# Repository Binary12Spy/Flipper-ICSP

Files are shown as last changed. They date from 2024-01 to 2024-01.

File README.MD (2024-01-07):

# Flipper-ICSP

Shout out to [Speexvocon](https://github.com/Speexvocon) for his [FlipperZeroKiCadPart](https://github.com/Speexvocon/FlipperZeroKiCadPart) making this project a whole lot easier!

I wanted to make a module for the Flipper Zero that works with [AVR Flasher](https://lab.flipper.net/apps/avr_isp) and simplifies hooking up a AVR microcontroller for flashing.  
This module simply formats the pins used by AVR Flasher into standard 10 position and 6 position ICSP headers with the option to choose between 3v3, 5v, or no supplied voltage.  


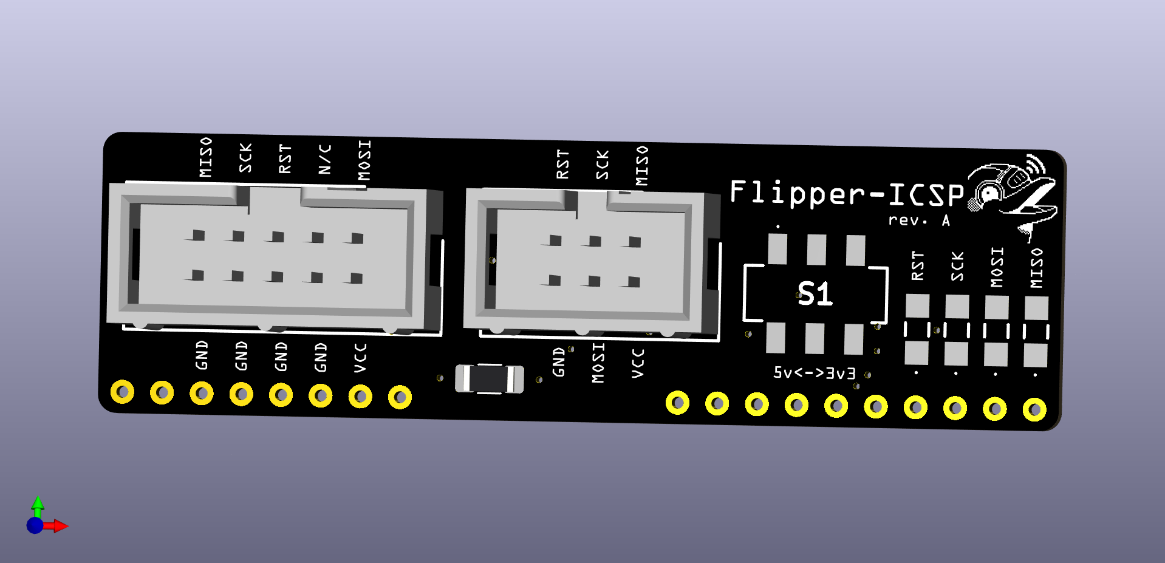
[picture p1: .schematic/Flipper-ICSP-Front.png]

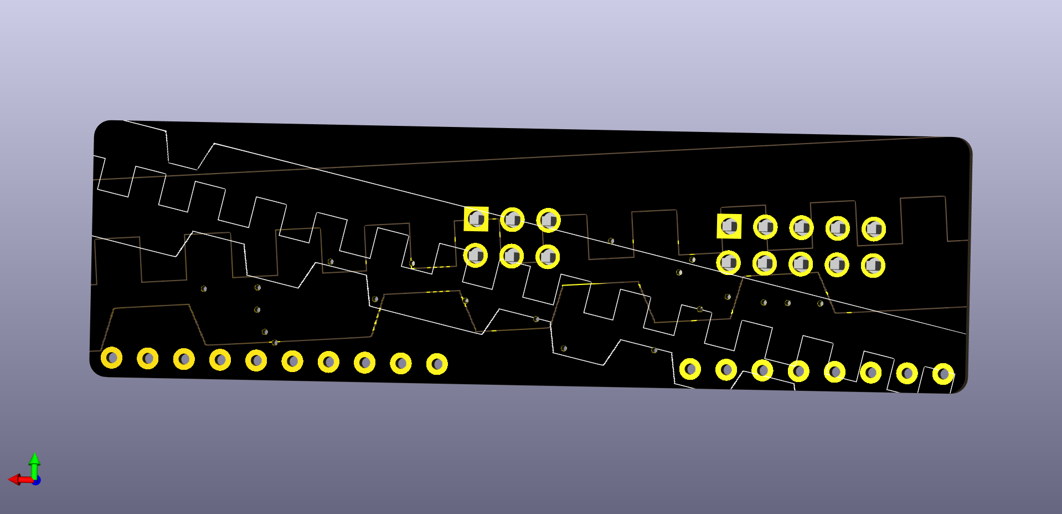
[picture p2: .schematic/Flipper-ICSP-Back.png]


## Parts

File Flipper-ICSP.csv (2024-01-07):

Id | Designator | Footprint | Quantity | Designation | Supplier and ref
1 | LED1,LED4,LED3,LED2 | 5990411127F | 4 | 599-0411-127F
2 | S1 | SLW9135352ASMT | 1 | SLW-913535-2A-SMT
3 | J2 | SHDR10W67P254_2X5_2032X916X922P | 1 | 1761681-3
4 | J3 | SHDR6W67P254_2X3_1524X916X922P | 1 | 1761681-1
5 | R1 | R_1206_3216Metric_Pad1.30x1.75mm_HandSolder | 1 | 220R

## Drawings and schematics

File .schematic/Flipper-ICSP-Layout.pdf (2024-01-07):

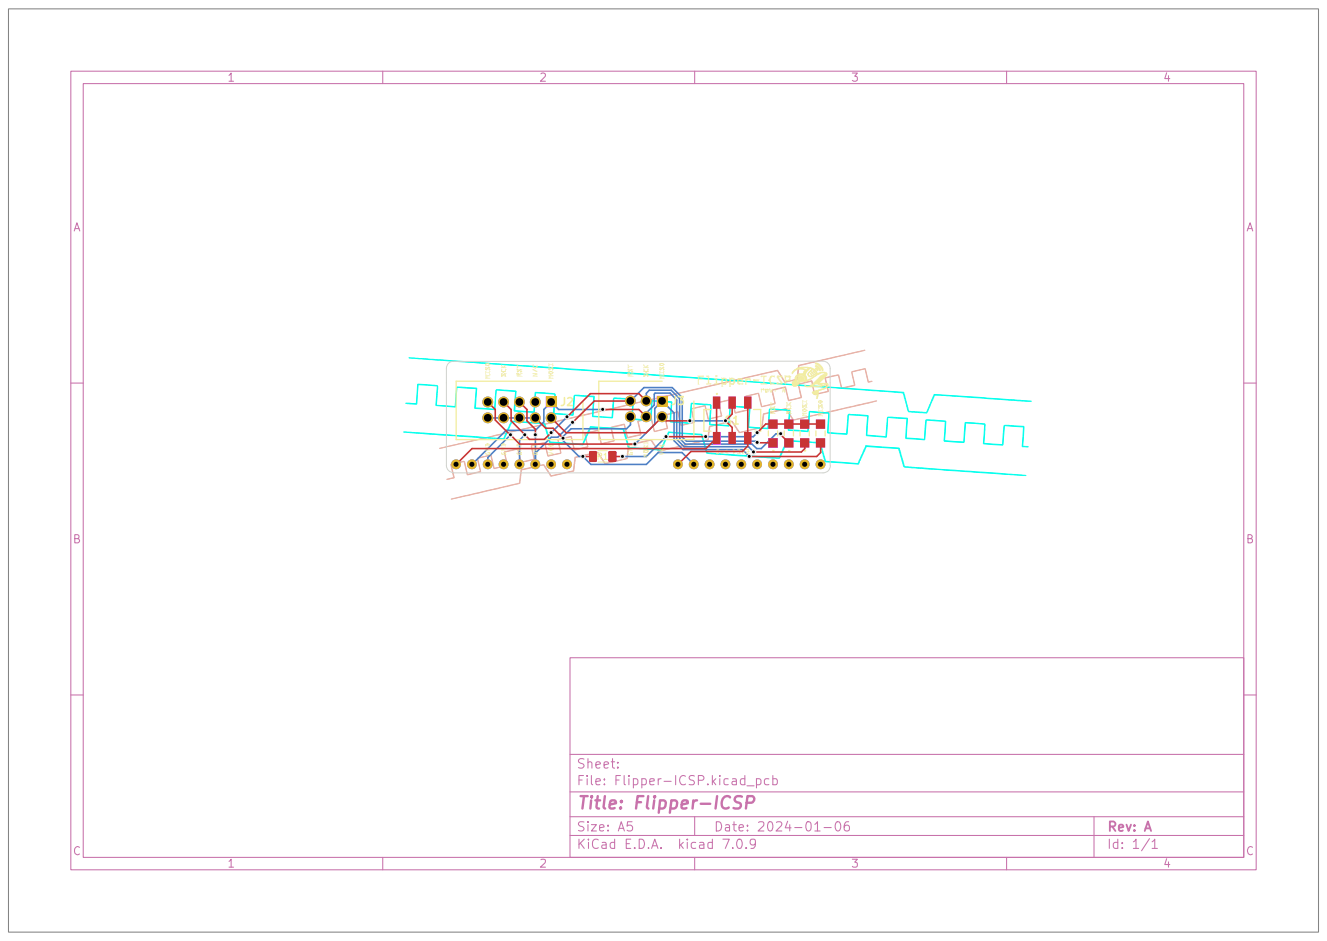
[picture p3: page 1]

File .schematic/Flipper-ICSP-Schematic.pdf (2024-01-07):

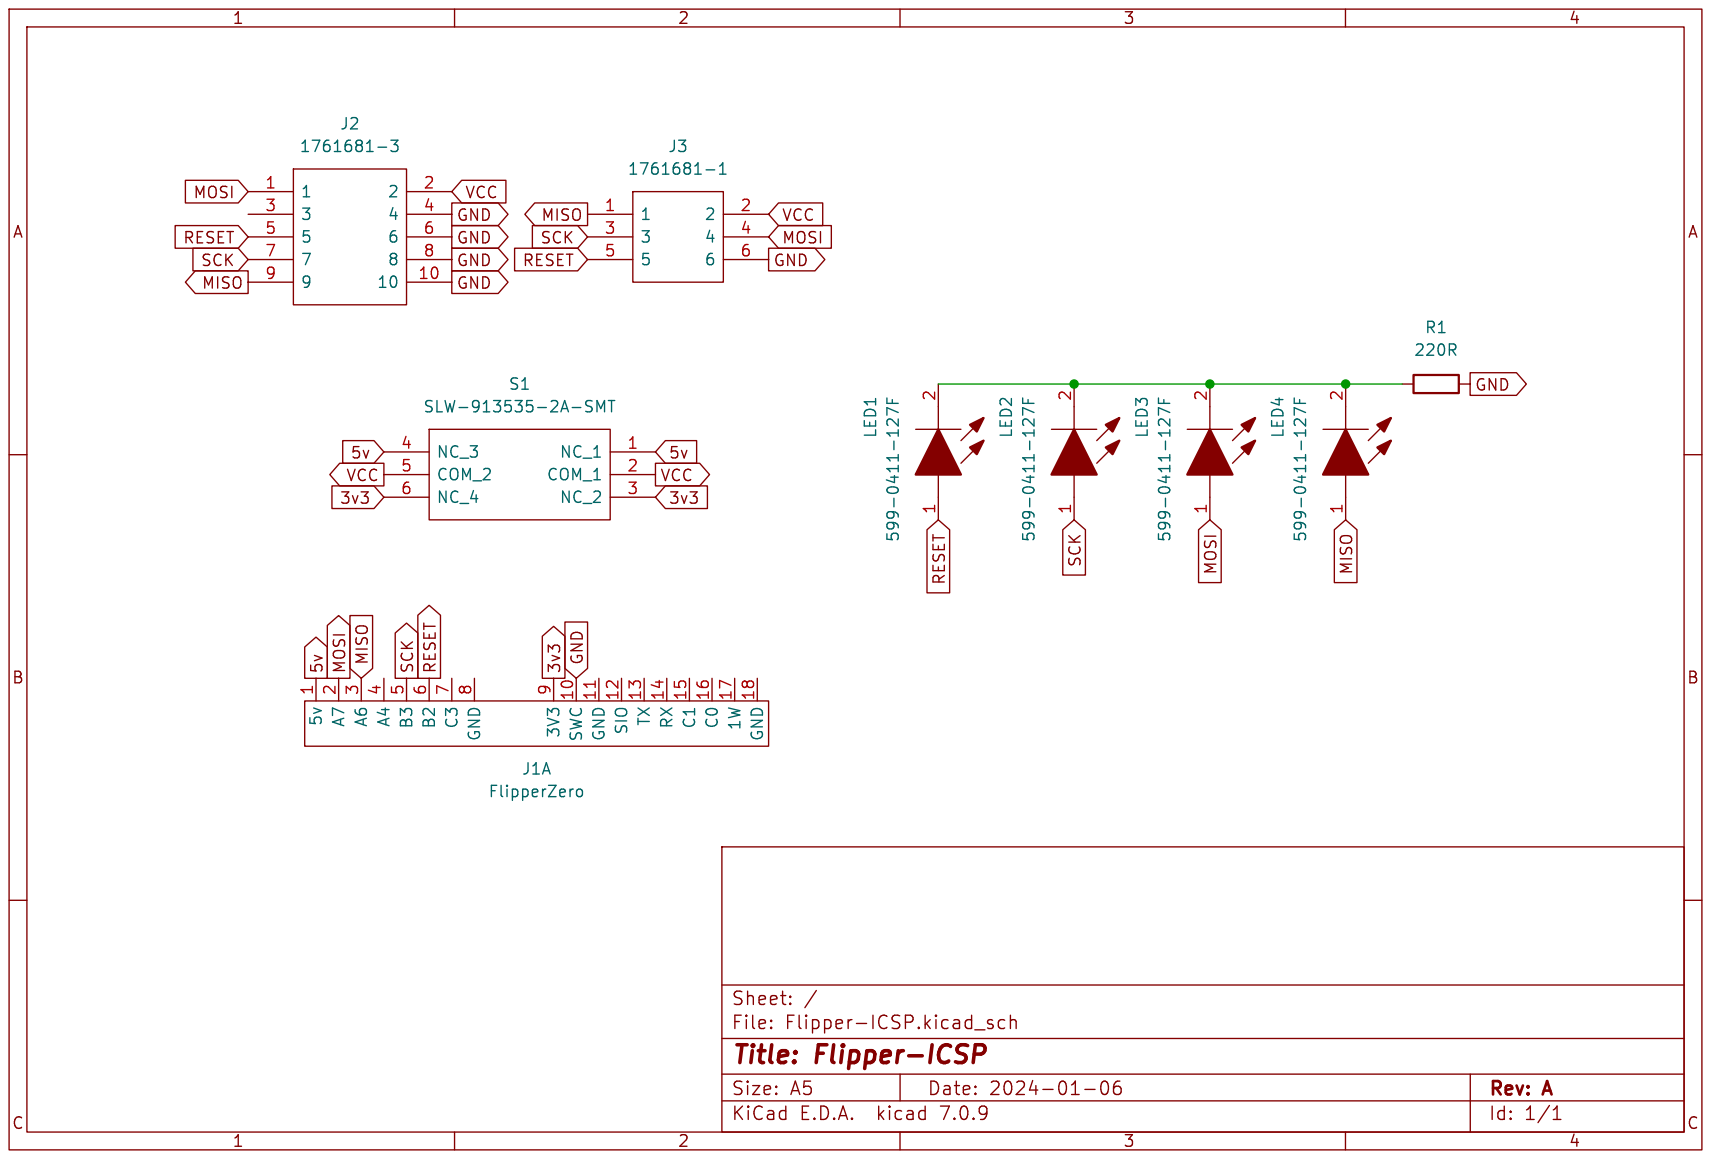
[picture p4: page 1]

Id: 1/1 Title: Flipper-ICSP

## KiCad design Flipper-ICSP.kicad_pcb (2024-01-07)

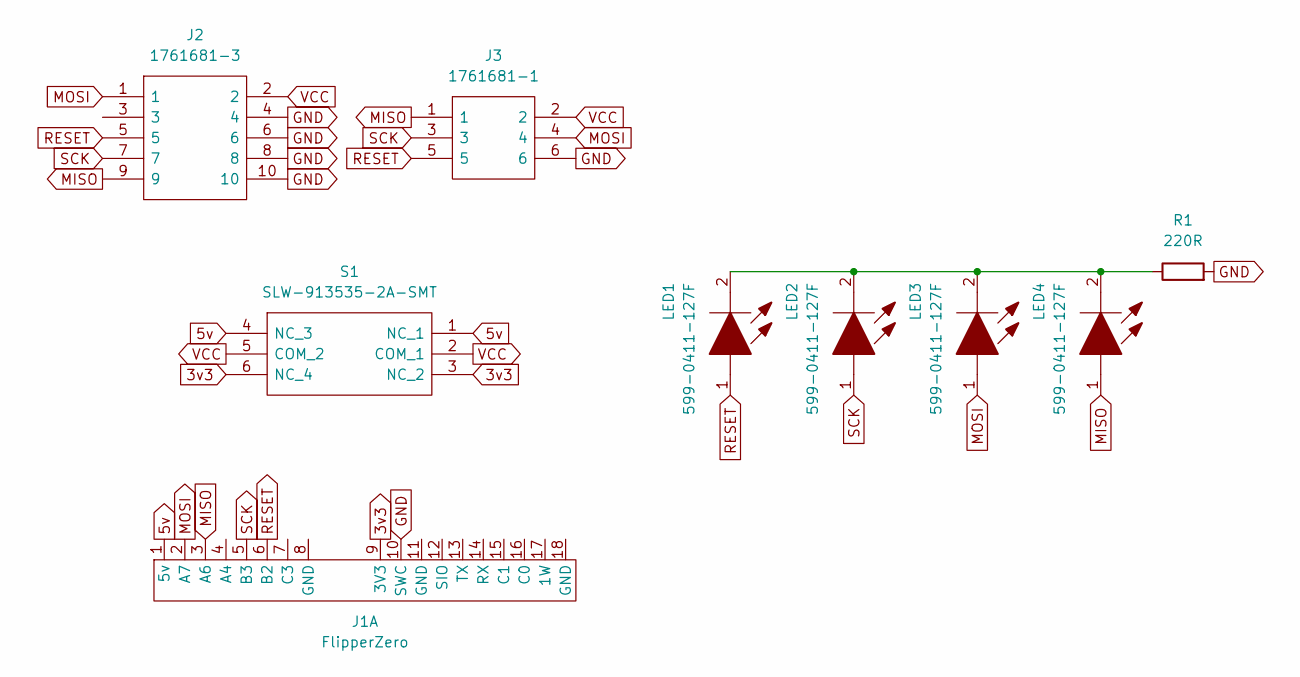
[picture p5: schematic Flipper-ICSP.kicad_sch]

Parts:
J1: FlipperZero; flipper zero through hole pins
J2: 1761681-3; SHDR10W67P254_2X5_2032X916X922P; Mouser Part Number 571-1761681-3
J3: 1761681-1; SHDR6W67P254_2X3_1524X916X922P; Mouser Part Number 571-1761681-1
LED1, LED2, LED3, LED4: 599-0411-127F; 5990411127F; Manufacturer_Part_Number 599-0411-127F
R1: 220R; R_1206_3216Metric_Pad1.30x1.75mm_HandSolder
S1: SLW-913535-2A-SMT; SLW9135352ASMT; Mouser Part Number 179-SLW-913535-2ASMT

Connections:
3v3: J1.9 (3V3), S1.3 (NC_2), S1.6 (NC_4)
5v: J1.1 (5v), S1.1 (NC_1), S1.4 (NC_3)
GND: J1.10 (SWC), J2.4, J2.6, J2.8, J2.10, J3.6, R1.2
MISO: J1.3 (A6), J2.9, J3.1, LED4.1
MOSI: J1.2 (A7), J2.1, J3.4, LED3.1
unnamed: LED1.2, LED2.2, LED3.2, LED4.2, R1.1
RESET: J1.6 (B2), J2.5, J3.5, LED1.1
SCK: J1.5 (B3), J2.7, J3.3, LED2.1
VCC: J2.2, J3.2, S1.2 (COM_1), S1.5 (COM_2)

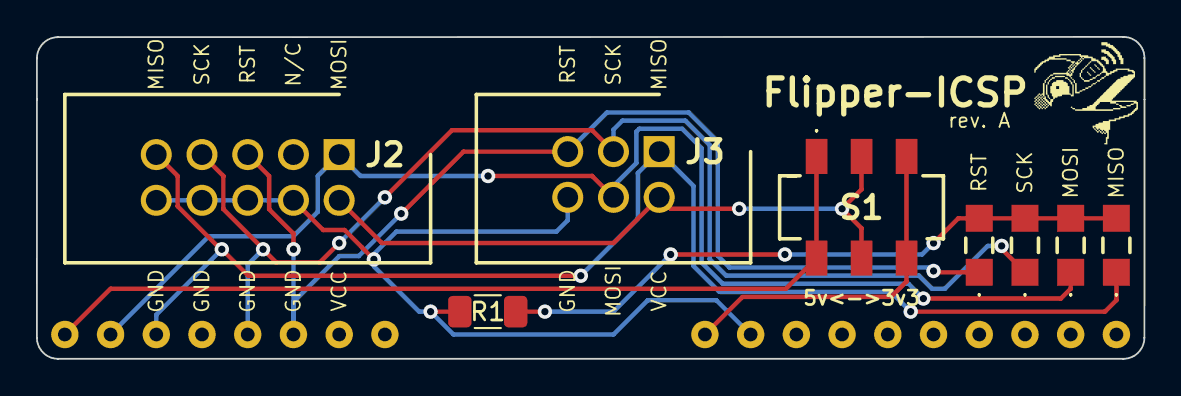
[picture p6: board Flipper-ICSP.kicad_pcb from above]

Board: 2 copper layers, 61.5 x 17.9 mm, 9 parts (0 on the bottom side), 9 nets.

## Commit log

2024-01-07 Updated project layout
    [Flipper-ICSP-B_Cu.gbr, Flipper-ICSP-B_Mask.gbr, Flipper-ICSP-B_Paste.gbr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]
2024-01-07 Added Schematic and PCB renderings
    [Flipper-ICSP.kicad_pcb]
